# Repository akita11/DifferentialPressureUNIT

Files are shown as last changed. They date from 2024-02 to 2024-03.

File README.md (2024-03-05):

# DiffPressute Unit

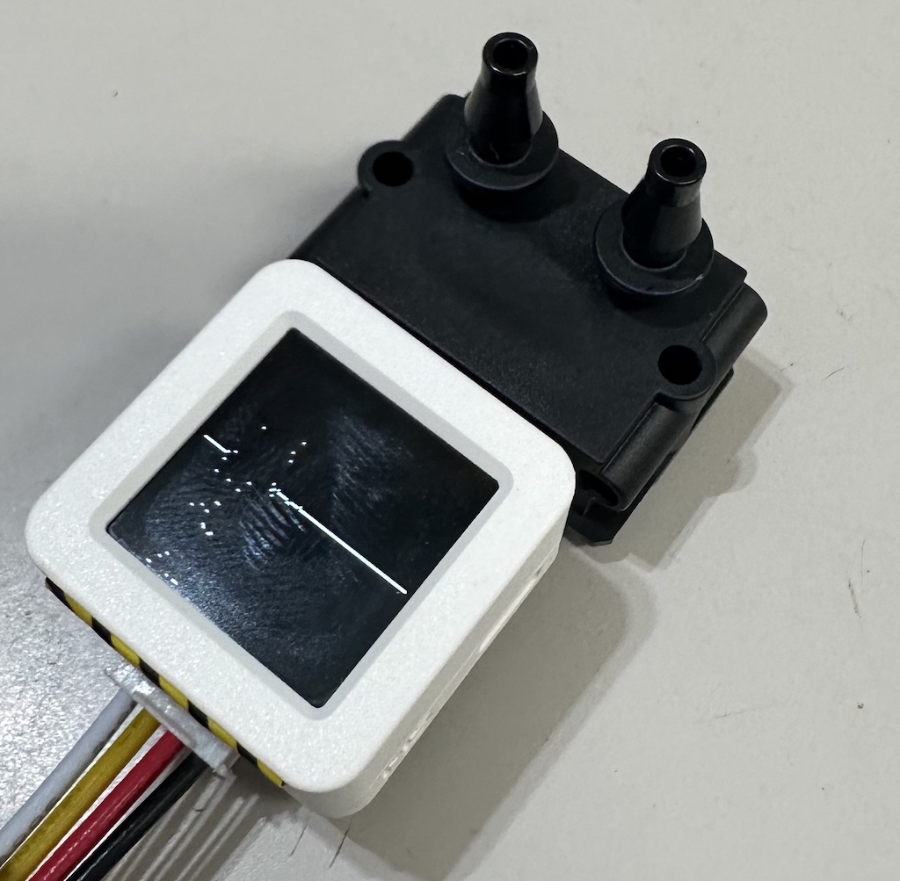
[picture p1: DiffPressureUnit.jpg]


空気の動きも検出できるSensirion社の高感度差圧センサ[SDP810-125Pa](https://www.sensirion.com/jp/products/product-catalog/SDP810-125Pa/)で2つの口の差圧を計測し、Groveポートから計測値を送出します。計測値は搭載するATOM S3上のディスプレイで確認できます。計測されたデータは、Core2等で利用できます。（[使用例](https://twitter.com/akita11/status/1758277269104336898)）

## 設定・操作

ATOM S3のボタン（ディスプレイ面）で以下のように設定を変更できます

- シングルクリック: 画面に表示されるグラフの感度（測定値の10倍（初期値：白）→100倍（緑）→1000倍（水色）→戻る）
- ダブルクリック: データ送出周波数（20ms(50Hz)→100ms(10Hz)→5ms(200Hz)→戻る）※グラフの動く速さが変わります

## UIFlowでの使い方

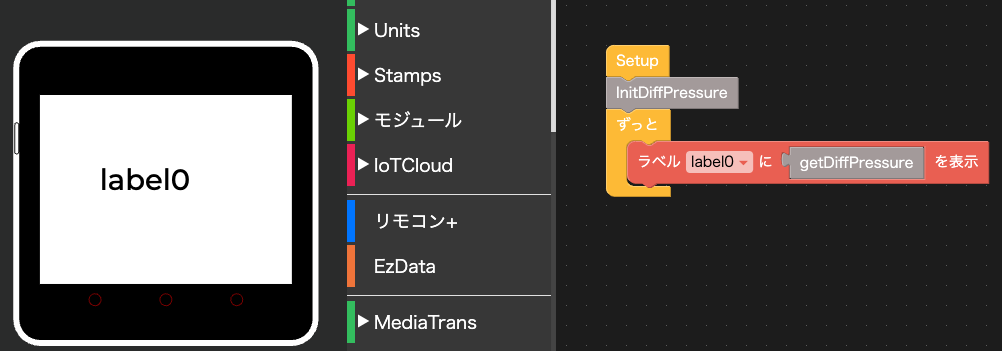
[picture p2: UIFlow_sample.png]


UIFlow用のカスタムブロックを用意してあります（現時点ではCore2専用ですがピン割当を変更することで他のCore Basic等でも利用可能）。

- Core2のPortAに、本UnitのGroveポート(ATOM S3上)からのGroveケーブルを接続します
- UIFlowの"Custom"の"Open *.m5b"から、UIFlow/DiffPressureUNIT.m5b を開く→Custom内に"DiffPressureUnit"が追加される
- UIFlow/DiffPressureUNIT_sample.m5f"を参考に利用できます
- getDiffPressureブロックで得られる値の単位は"Pa"です。

## UART通信プロトコル

- UARTプロトコル: 115200bps, N81
- データ形式: 計測値（-32768〜+32767:符号付き16bit）の文字列＋LF('\n')

この「計測値」は、SDP810-125Paから出力される計測値です。実際の圧力への換算式はデータシートにあり、「計測値 ÷ 240 [Pa]」となります（例：計測値で"240"が1Pa）。なおSDP810-125Paのデータシートによれば、ゼロ点精度は0.08Pa、ゼロ点再現性は0.04Paです。（前述のUIFlow用カスタムブロックでは、この換算式を用いて単位[Pa]で計測値が得られます）

## Author

Junichi Akita (akita@ifdl.jp, @akita11)

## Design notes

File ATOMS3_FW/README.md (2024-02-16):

Get data from Differential Pressure Sensor, SDP810-125Pa, draw its graph, and send it via Grove's UART, using ATOMS3.

Usage: https://twitter.com/akita11/status/1758277269104336898

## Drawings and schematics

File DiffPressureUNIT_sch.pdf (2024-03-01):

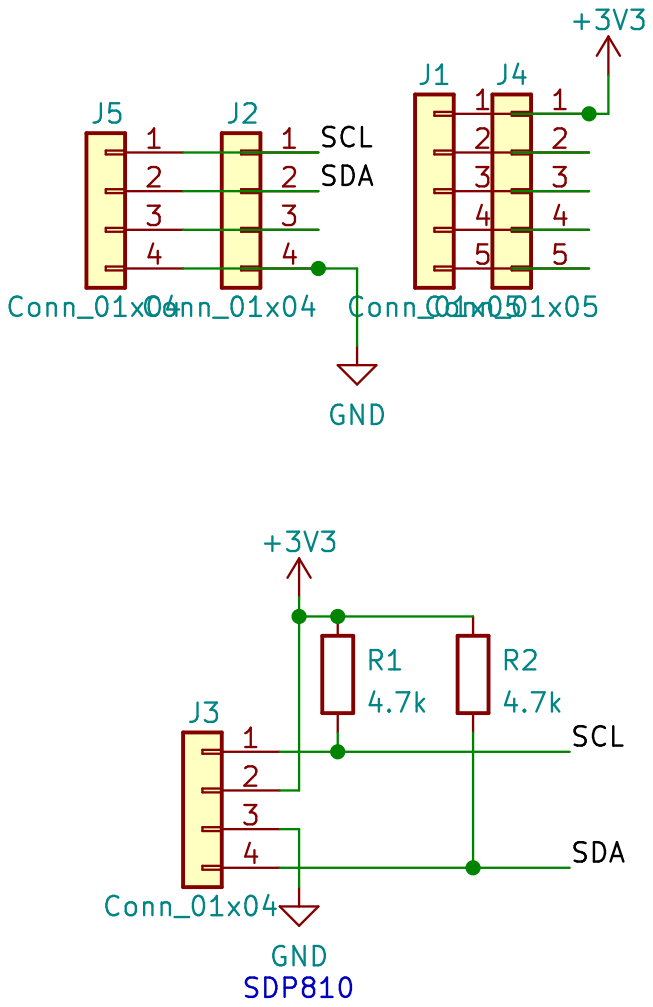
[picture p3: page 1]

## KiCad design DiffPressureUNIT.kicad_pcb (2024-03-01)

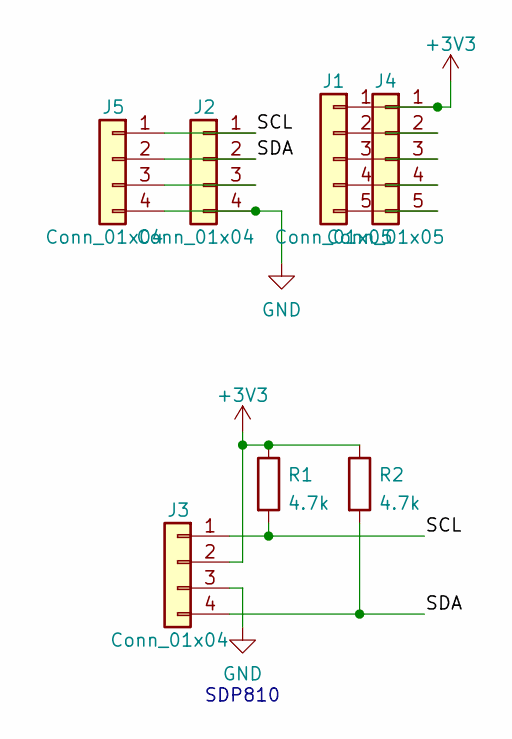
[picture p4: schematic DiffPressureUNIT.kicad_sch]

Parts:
J1, J4: Conn_01x05; PinHeader_1x05_P2.54mm_Vertical
J2, J5: Conn_01x04; PinHeader_1x04_P2.54mm_Vertical
J3: Conn_01x04; PinSocket_1x04_P2.00mm_Vertical
R1, R2: 4.7k; R_0603_1608Metric

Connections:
+3V3: J1.1, J3.2, J4.1, R1.1, R2.1
/SCL: J2.1, J3.1, J5.1, R1.2
/SDA: J2.2, J3.4, J5.2, R2.2
GND: J2.4, J3.3, J5.4
unnamed: J1.2, J4.2
unnamed: J1.3, J4.3
unnamed: J1.4, J4.4
unnamed: J1.5, J4.5
unnamed: J2.3, J5.3

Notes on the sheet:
SDP810

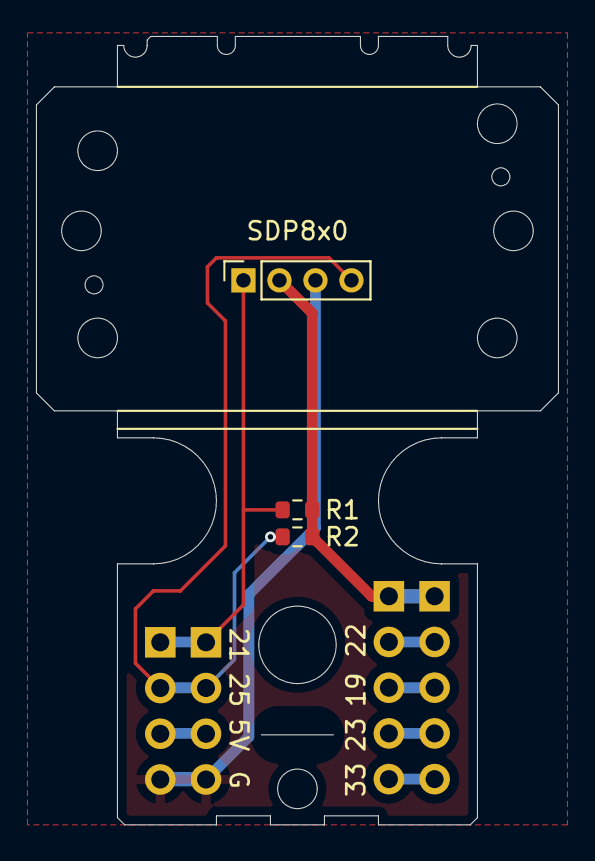
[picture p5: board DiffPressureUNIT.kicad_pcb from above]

Board: 2 copper layers, 29.0 x 43.8 mm, 7 parts (0 on the bottom side), 9 nets.

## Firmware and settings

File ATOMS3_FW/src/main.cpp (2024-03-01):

#include <Arduino.h>
#include <M5Unified.h>
#include <Wire.h>

#define I2C_ADDR_SDP810 0x25

#define NX 128
uint8_t p = 0;
uint8_t val[NX];
uint8_t modeS = 1;
#define N_SPEED 3
uint8_t wait[] = { 5, 20, 100 };
uint8_t v0 = 64;

#define N_MAG 3
uint8_t modeM = 0;
float mags[] = {10, 100, 1000};
uint16_t color;
uint16_t colors[] = { WHITE, GREEN, CYAN };

// LCD: 128x128
void setup() {
  auto cfg = M5.config();
  M5.begin(cfg);
  M5.Lcd.clear();
//  Serial.begin(115200);
  Serial.begin(115200, SERIAL_8N1, 2, 1); // RX/TX (Grove)
//  Serial2.begin(115200, 2, 1); // RX/TX (Grove)
  Wire.begin(38, 39); // SDA, SCL
  Wire.beginTransmission(I2C_ADDR_SDP810);
  Wire.write(0x36); Wire.write(0x1e); // diff. pres. continuous, no average
  Wire.endTransmission();
}

// 2's complement
int conv_2s(uint16_t d)
{
  if (d & 0x8000) return(- ((~d & 0x7fff) + 1));
  else return(d);
}

void loop() {
  uint8_t px = p;
  uint8_t dp = 0;
  uint8_t dat[16];
 
//  Wire.requestFrom(I2C_ADDR_SDP810, 9);
//  while(Wire.available() && dp < 9) dat[dp++] = Wire.read();
  Wire.requestFrom(I2C_ADDR_SDP810, 3);
  while(Wire.available() && dp < 3) dat[dp++] = Wire.read();
 
  uint16_t DPb, Tempb, SFb;
  DPb   = dat[0] << 8 | dat[1];
//  Tempb = dat[3] << 8 | dat[4];
//  SFb   = dat[6] << 8 | dat[7];
//  Serial.print(DPb, HEX); Serial.print(" ");
//  Serial.print(Tempb, HEX); Serial.print(" ");
//  Serial.print(SFb, HEX); Serial.print(" | ");
  int DPi, Tempi, SFi;
  DPi   = conv_2s(DPb);
//  Tempi = conv_2s(Tempb);
//  SFi   = conv_2s(SFb);
//  Serial.print(DPi); Serial.print(" ");
//  Serial.print(Tempi); Serial.print(" ");
//  Serial.print(SFi); Serial.print(" | ");
  float DP, Temp;
  DP = (float)DPi / 240.0;
//  Temp = (float)Tempi / 200.0;
//  Serial.print(t++); Serial.print(" ");
//  Serial.print(DP); Serial.print(" ");
//  Serial.print(Temp); Serial.println("");

  int vn = (int)(DP * mags[modeM]) + 64;
  if (vn < 0) vn = 0;
  if (vn > 127) vn = 127;
//  printf("%d %f %f\n", vn, mags[modeM], DP); 
//  Serial.printf("%04x\n", (DPi & 0xffff));
  Serial.printf("%d\n", (DPi & 0xffff));
//  Serial.printf("%f\n", DP);
//  Serial.printf("%d %f\n", vn, DP);
//  Serial.printf("%c%c%c%c", 0x55, 0xaa, dat[0], dat[1]);
  val[px] = vn;
  color = colors[modeM];
  for (uint8_t x = 0; x < NX; x++){
    M5.Lcd.drawFastVLine(x, 0, 128, BLACK);
    M5.Lcd.drawPixel(x, val[px], color);
    px = (px + 1) % NX;
  }
  p = (p + 1) % NX;
  M5.update();
  if (M5.BtnA.wasDoubleClicked()){
    modeS = (modeS + 1) % N_SPEED;
  }
  if (M5.BtnA.wasSingleClicked()){
    modeM = (modeM + 1) % N_MAG;
  }
  delay(wait[modeS]);
}
